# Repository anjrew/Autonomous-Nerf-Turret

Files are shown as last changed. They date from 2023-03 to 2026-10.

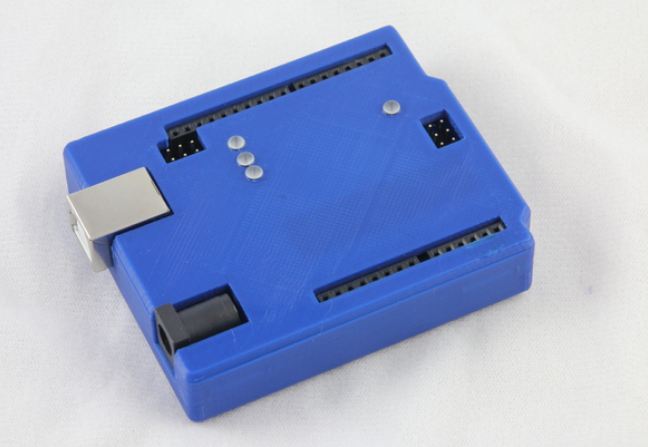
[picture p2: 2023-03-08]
cad/arduino-uno-case/Capture.JPG

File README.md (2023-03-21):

# Autonomous Nerf Turret

A project dedicated to creating a fully autonomous, AI-powered Nerf gun. The turret is equipped with a camera, allowing it to detect and track human targets. 

## Getting started

This project was built on MacOS on top of these main dependencies:
  - bash
  - conda
  - [CMake](https://cmake.org/download/)

 If these are installed then run the following command in the project root to get the rest of the dependencies and setup the virtual environment:
 ```bash
source bin/init.sh
 ```

 When coming back to the project to reactivate the environment run the following in the project root:
 ```bash
 source bin/activate.sh
 ```

## Important info

The files and folders in this project depend on each other and this means that the folder structure is important. If any folder structure or file is changed it could break some functionality.

## Project structure

This project is driven by domain where each domain component lies in a folder in the 'components' directory. Each sub domain folder contains files that relate to the part of the project associated with that domain.

For example:
  - The **camera_vision** folder contains files related to the computer vision tasks associated with face tracking.
  - The **arduino** folder contains files related to the task of moving and controlling the stepper motor through the Arduino

  ## Versions

  - 1 - Stepperonline Nema 17 Stepper Motor, 45 Ncm, 1.5 A, 12 V, 39 mm, 4-Wire 1.8 Deg Stepper Motor with 1 m Wire for 3D Printers:
    - When firing under full load with stepper servo and gun the circuit pulls around 1.8A when running and 2.1A when starting up
    - Of this the gun motors take up around 1.1A at full speed and 1.9A when starting up
    - On stand still the circuit uses 0.08A

  ## Good combination configurations

| HEADLESS | Skip Frames | IMG Comp | Y-speed,smooth,lim | X-speed,smooth,lim | target_type | faces | objects | model |
|---|---|---|---|---|---|---|---|---|
| True | 500 | 4x | 2,1,10 | 30,1,60 | person | True  | True | yolov8n-seg.pt |

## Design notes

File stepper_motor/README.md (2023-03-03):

# Stepper control notes

- Pulsing the **step** pin on the stepper motor driver will cause the motor to move one step
- The longer the time between pulses the slower the step will take place
- Change the direction pin between high/low to change direction of the spin to clockwise vs anti clockwise

# Key notes
- Input voltage is set to 12.5v

## Setup 

Before you start programming your Arduino and start using the driver there is one very important thing you need to do that a lot of people forget: set the current limit!

You must measure a reference voltage and adjust the on-board potentiometer accordingly. You will need a small screwdriver, a multimeter to measure the reference voltage, and alligator test leads

Image of how to do it

To measure the reference voltage, the driver needs to be powered. The A4988 only needs power via VDD (5V) and you need to connect RST and SLP together, otherwise the driver won’t turn on. It’s best to disconnect the stepper motor while you do this.

The next step is to calculate the current limit with the following formula: **Current Limit = Vref / (8 × Rcs)**

Refactored to get the Vref this is **Vref = Current Limit * (8 × Rcs)**

The Rcs is the current sense resistance. If you bought a A4988 driver from Pololu before January 2017, the Rcs will be 0.050 Ω. Drivers sold after that have 0.068 Ω current sense resistors.

The calculation for the Vref that was acquired on the first time was:
Vref = 0.380 = 0.7A * (8 * 0.068)

## Communication over serial

A raw none stringified JSON string can be sent over serial and be received by the Arduino with optional direction and speed properties.

## Calculating RPM value

The motor here has 200 steps in one revolution
So 200 steps per second would equal 60 RPM

So time per step in seconds = 60 * steps_per_revolution
timeper step

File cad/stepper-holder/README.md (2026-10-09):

# Stepper motor holder (NEMA 17 / 17HS4023)

Parametric OpenSCAD holder for the elevation stepper motor used by the turret.

## Files

- `stepper_holder.scad` — parametric source; edit the values at the top
- Export an STL with OpenSCAD: open the file, press **F6** (render), then
  **File → Export → Export as STL**

## Default dimensions

| Feature | Value |
| --- | --- |
| Motor face | 42.3 mm (17HS4023) |
| Bolt pattern | 31 mm square, M3 (3.4 mm clearance) |
| Centring boss clearance | 22.5 mm |
| Shaft clearance | 8 mm |
| Plate thickness | 5 mm |
| Cradle wall height | 18 mm |

The holder has a face plate with the NEMA 17 bolt pattern, a three-sided
cradle that holds the motor body (open on top for drop-in and at the back for
wiring), and two side flanges with screw slots for mounting to the turret.

Tune the parameters for your exact motor, then re-render and export.

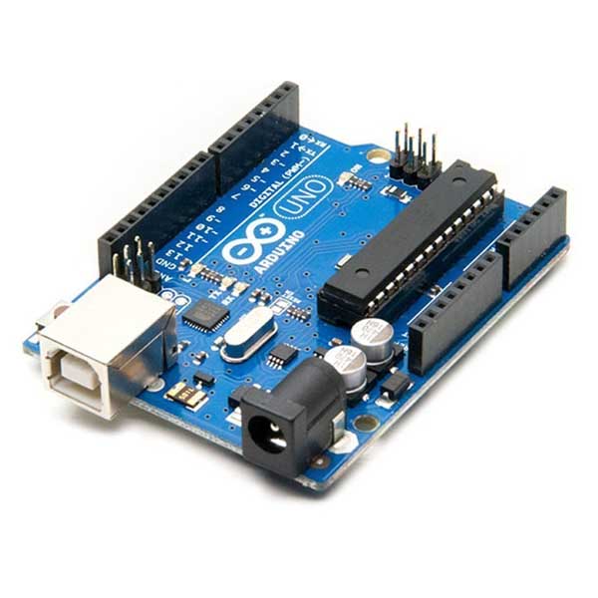
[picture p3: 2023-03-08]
cad/arduino-uno-case/uno_r3.jpg

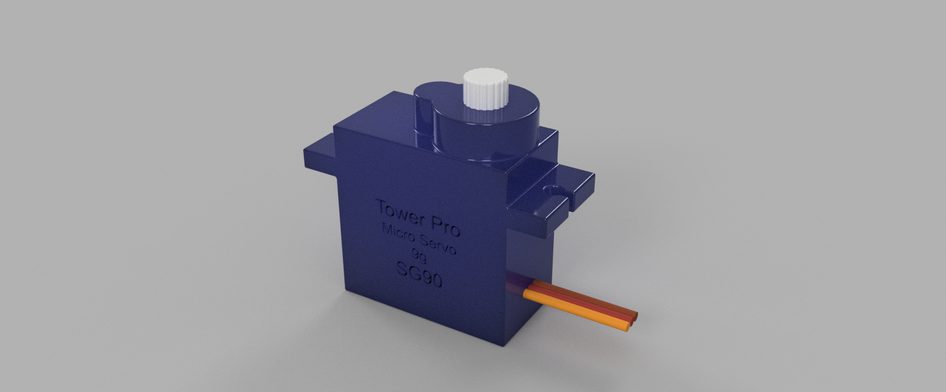
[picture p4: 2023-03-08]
cad/servo-sg90/Tower Pro SG90 Servo v7.png

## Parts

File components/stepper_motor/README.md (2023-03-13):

# Stepper control notes

- Pulsing the **step** pin on the stepper motor driver will cause the motor to move one step
- The longer the time between pulses the slower the step will take place
- Change the direction pin between high/low to change direction of the spin to clockwise vs anti clockwise

# Key notes
- Input voltage is set to 12.5v

## Setup 

Before you start programming your Arduino and start using the driver there is one very important thing you need to do that a lot of people forget: set the current limit!

You must measure a reference voltage and adjust the on-board potentiometer accordingly. You will need a small screwdriver, a multimeter to measure the reference voltage, and alligator test leads

Image of how to do it

To measure the reference voltage, the driver needs to be powered. The A4988 only needs power via VDD (5V) and you need to connect RST and SLP together, otherwise the driver won’t turn on. It’s best to disconnect the stepper motor while you do this.

The next step is to calculate the current limit with the following formula: **Current Limit = Vref / (8 × Rcs)**

Refactored to get the Vref this is **Vref = Current Limit * (8 × Rcs)**

The Rcs is the current sense resistance. If you bought a A4988 driver from Pololu before January 2017, the Rcs will be 0.050 Ω. Drivers sold after that have 0.068 Ω current sense resistors.

The calculation for the Vref that was acquired on the first time was:
Vref = 0.380 = 0.7A * (8 * 0.068)

## Communication over serial

A raw none stringified JSON string can be sent over serial and be received by the Arduino with optional direction and speed properties.

## Calculating RPM value

The motor here has 200 steps in one revolution
So 200 steps per second would equal 60 RPM

So time per step in seconds = 60 * steps_per_revolution

## Key points

Here are some key points after testing the motor at different half step speeds

- The slowest the motor can go is 16000us between each half step
  - That means that the slowest the motor can do one step is 32000us
  - So 32000us x 200 Steps for one revolution is 6400000us
  - That means that it does one revolution in 6.4 seconds at min speed
  - Max Revolutions per minute = 60 seconds/0.16 seconds = 375 revolutions per minute (RPM)
  - Min Revolutions per minute = 60 seconds/6.4 seconds = 9.375 revolutions per minute (RPM)

- The fastest the motor can go is 400us between each half step
  - That means that the fastest the motor can do one step is 800us
  - So 800us x 200 Steps for one revolution is 160000us
  - That means that it does one revolution in 0.16 seconds at max speed
  - Max Revolutions per minute = 60 seconds/0.16 seconds = 375 revolutions per minute (RPM)

- In summery the min/max RPM is ~9rpm/375rpm 

## Sources of information
 - See the [Documentation folder](./documentation/)
 - For info on the 2N3904 Resistor see [this](https://www.homemade-circuits.com/understanding-transistor-2n3904/) link
 - [Servo Motor](https://www.amazon.de/dp/B09WRBHSVD?ref=ppx_yo2ov_dt_b_product_details&th=1) for azimuth 
 - [LM2596 Buck Converter](https://www.amazon.de/Yizhet-LM2596-Buck-Converter-3-0/dp/B0823P6PW6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)

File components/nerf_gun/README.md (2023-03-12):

# Nerf gun

The Nerf gun used is a [Hyper-Fire Elite](https://www.amazon.de/-/en/Hasbro-N-Strike-Hyper-Fire-Blaster-B5573F03/dp/B01N2GMZ3M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)

Gun Image

Info:
 - [Video](https://www.youtube.com/watch?v=H6EAR7Sc_Ms) on modification showing how to dismantle and wiring information
 - [5v Relay](https://www.reichelt.de/de/de/entwicklerboards-relais-modul-5-v-srd-05vdc-sl-c-debo-relay-5v-p239148.html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)

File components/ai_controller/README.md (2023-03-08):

# AI controller

The AI controller subscribes to the output of the camera vision and sends controls to the serial driver component:

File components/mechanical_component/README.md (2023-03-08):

# Mechanical Design

Here you will find the CAD design that was made in fusion 360 and other components that went into designing the frame pullies and bearings

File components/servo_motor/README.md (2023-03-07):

# Servo motor

[The servo motor](https://m.media-amazon.com/images/I/91KkRAtEPSL._AC_SL1500_.jpg)

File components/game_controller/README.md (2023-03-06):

# Game controller

The game controller component takes input from a game controller in order to send messages to the serial driver to control the gun turret manually.

This controller was made with the GC-1 Series Wired controller in mind. Model NO: GC102

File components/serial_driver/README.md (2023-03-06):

# Driver

The driver is responsible for managing the inputs from whatever controller source and forwarding the messages to the motors via serial

Examples of controller sources are:
  - ai model
  - game controller

The driver is a server that listens on a port and waits for commands from any controller and executes forwards the commands tot he

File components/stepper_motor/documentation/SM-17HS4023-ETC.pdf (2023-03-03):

# SM-17HS4023

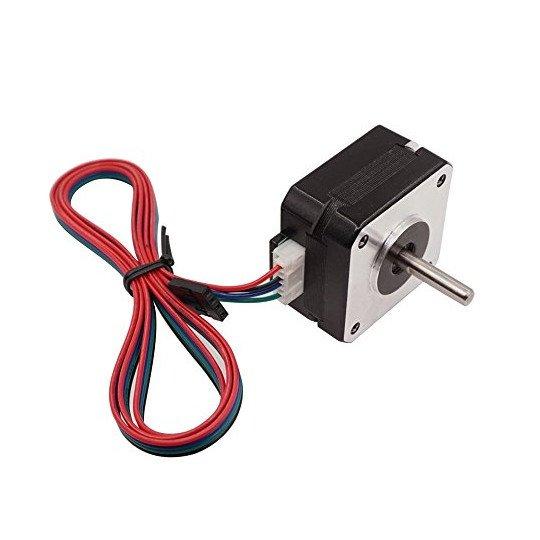
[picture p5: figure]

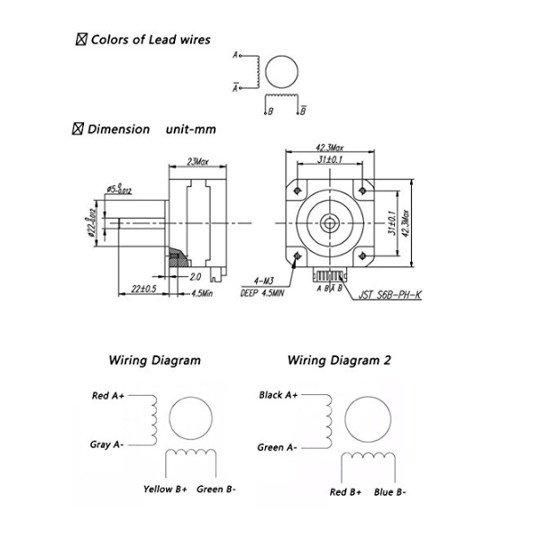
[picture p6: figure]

HARDWARE

- Shaft diameter 5mm
- Shaft Length 21mm
- 4 wires / 2 Phase
- Voltage: 12 V
- Current: 0.7 A / Phase
- Resistance: 4.0 ± 10% Ω / Phase
- Inductance: 3.2 ± 20% mH / Phase
- Holding Torque: 14 N. cm
- Insulation Class: B
- Step Angle: 1.8 ± 5% / Step
- Item Size: 42 * 42 * 23mm

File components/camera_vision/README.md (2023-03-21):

# Vision

This code includes computer vision algorithms for object detection and tracking. 

## Info
  - A [video](https://www.youtube.com/watch?v=5yPeKQzCPdI&list=PLVlbw1IZ2gnswgwYW9jXkEz43f3j7qs25&index=77) of how to use the face recognition library 
  - A guide on setting up the [YOLO object detection](https://docs.ultralytics.com/tasks/detect/) 
  - Speed optimization for inference with script parameters:
    - Skip 10 frames
    - Use 4x compression

## Image processing times

These experiments were made on 2018 Macbook pro and processing as a video feed:

| MODEL | Task | Preprocessing  |  Inference | Post processing | Detect total time  | Loop total time  | Showing camera |
|---|---|---|---|---|---| ---| --- |
| yolov8n-seg.pt  | Detection | +/- 1ms mean | +/- 220ms mean | +/- 1ms mean | +/- 222ms mean | +/- 222ms mean | [x] |
| yolov8n-seg.pt  | Detection | unknown | unknown | unknown | unknown | +/- 230ms mean | [x] |
| yolov8n.pt | Detection | +/- 1ms mean | +/- 168s mean | +/- 1ms mean | +/- 170ms mean | +/- 170ms mean | [x] |

The findings indicate the most of the image processing time is in inference and the pre and post processing time is negligible.
Segmentation takes 30% more time to process than bounding box detection.

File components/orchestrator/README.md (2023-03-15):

# Orchestrator

This folder contains files related to the orchestrator which manages all the other services together to create complete solutions

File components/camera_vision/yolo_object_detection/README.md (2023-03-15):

# Yolo Object Detection

## Notes

  - How to improve performance with library [Link](https://github.com/nebuly-ai/nebullvm/blob/main/notebooks/speedster/pytorch/Accelerate_PyTorch_YOLOv8_with_Speedster.ipynb)
  - How to improve performance by exporting [Link](https://docs.ultralytics.com/modes/export/)

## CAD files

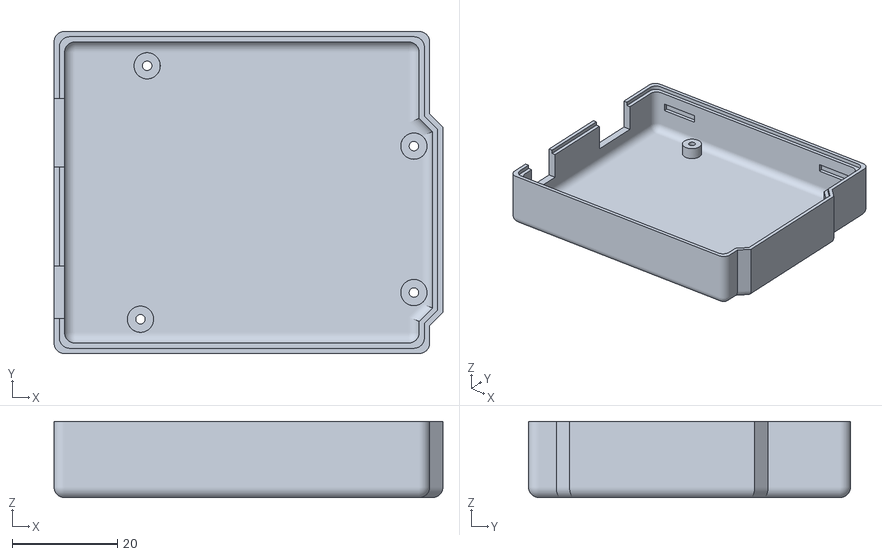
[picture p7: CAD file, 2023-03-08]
cad/arduino-uno-case/arduino_uno_bottom.stl
74.1 x 61.3 x 14.5

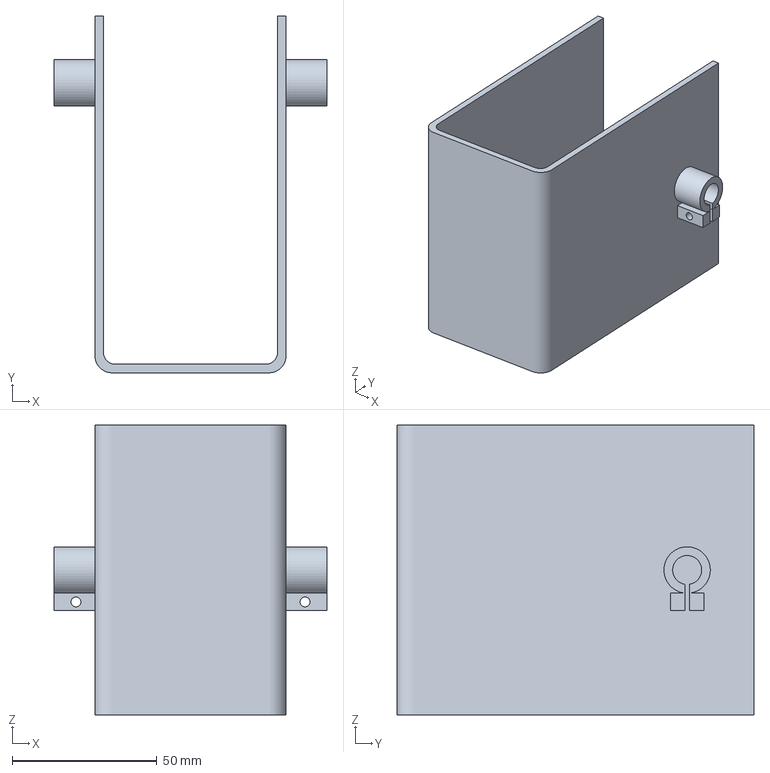
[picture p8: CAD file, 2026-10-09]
cad/gun-cradle/gun_cradle.3mf
94.0 x 123.0 x 100.0 mm

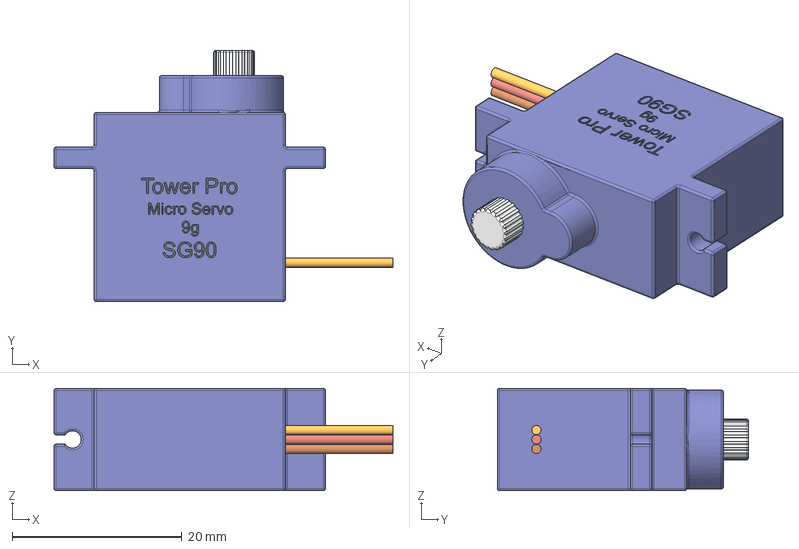
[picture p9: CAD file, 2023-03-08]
cad/servo-sg90/Tower Pro SG90 Servo v7.step
40.0 x 29.7 x 12.1 mm

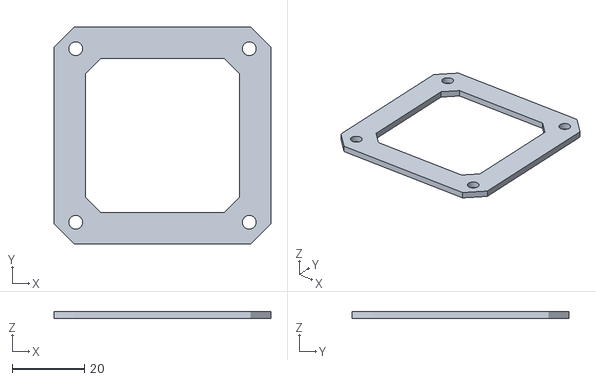
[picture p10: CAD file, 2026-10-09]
cad/stepper-holder/stepper_outer_plate.stl
60.0 x 60.0 x 2.00

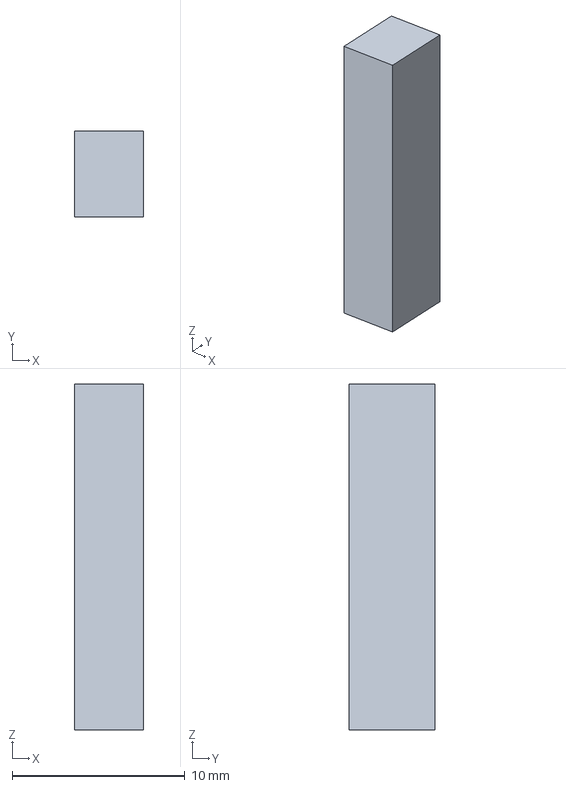
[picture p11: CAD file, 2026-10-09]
cad/trigger-block/trigger_block.3mf
4.00 x 5.00 x 20.0 mm

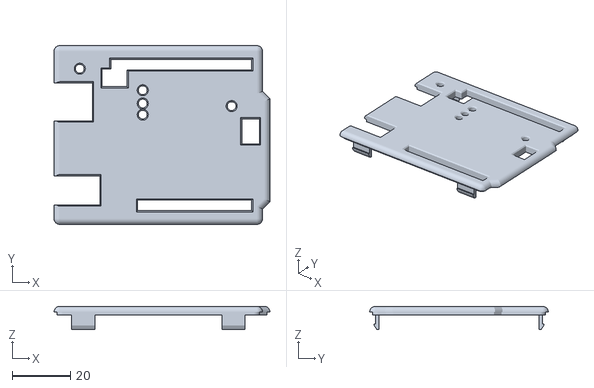
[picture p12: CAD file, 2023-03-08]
cad/arduino-uno-case/arduino_uno_top.stl
74.1 x 61.3 x 8.00

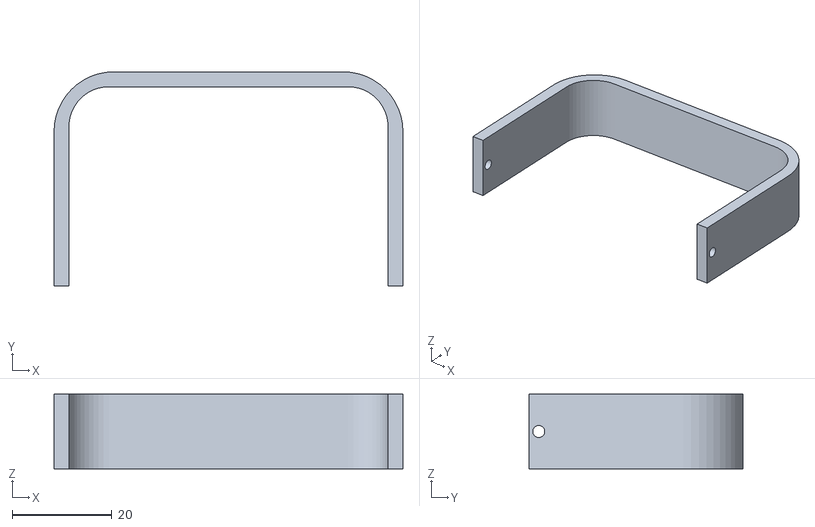
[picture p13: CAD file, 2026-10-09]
cad/gun-cradle/gun_cradle_plain_40.stl
70.0 x 43.0 x 15.0

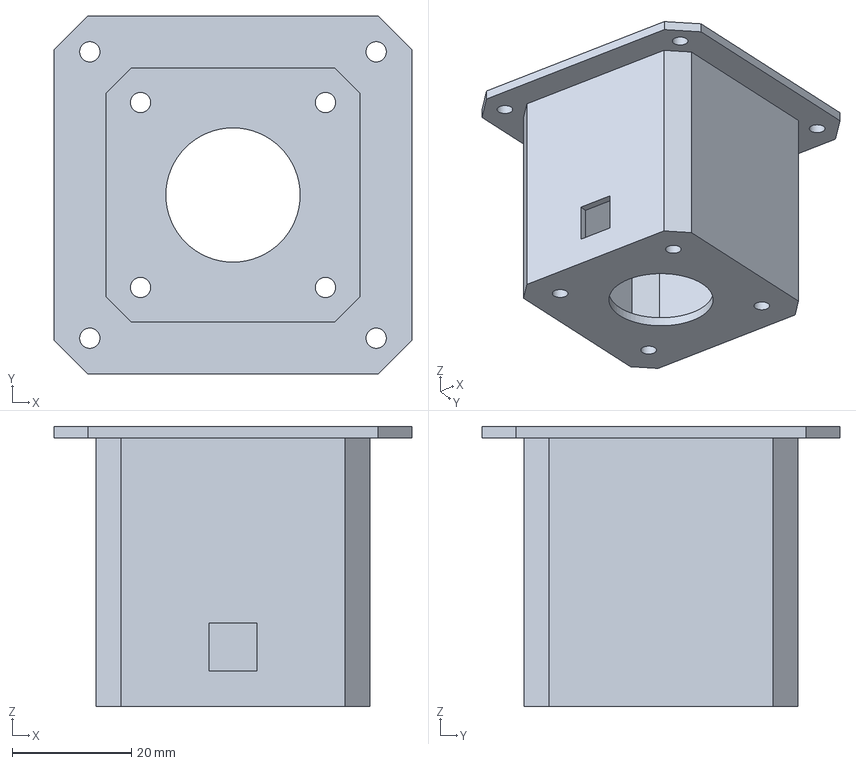
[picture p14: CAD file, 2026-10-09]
cad/stepper-holder/stepper_holder.3mf
60.0 x 60.0 x 47.0 mm

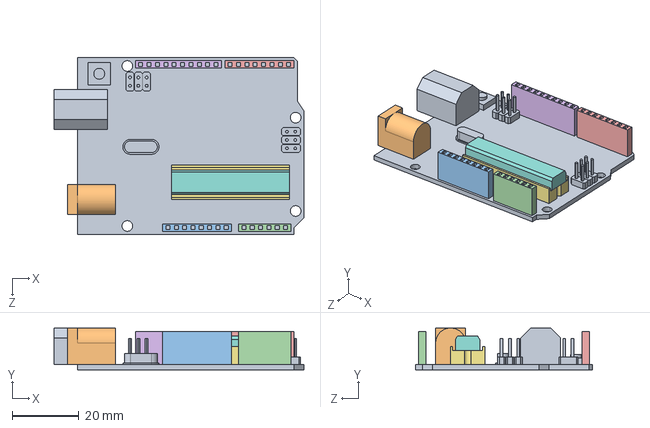
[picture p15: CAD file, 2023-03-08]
cad/arduino-uno-case/uno.STEP
75.0 x 12.6 x 53.0 mm

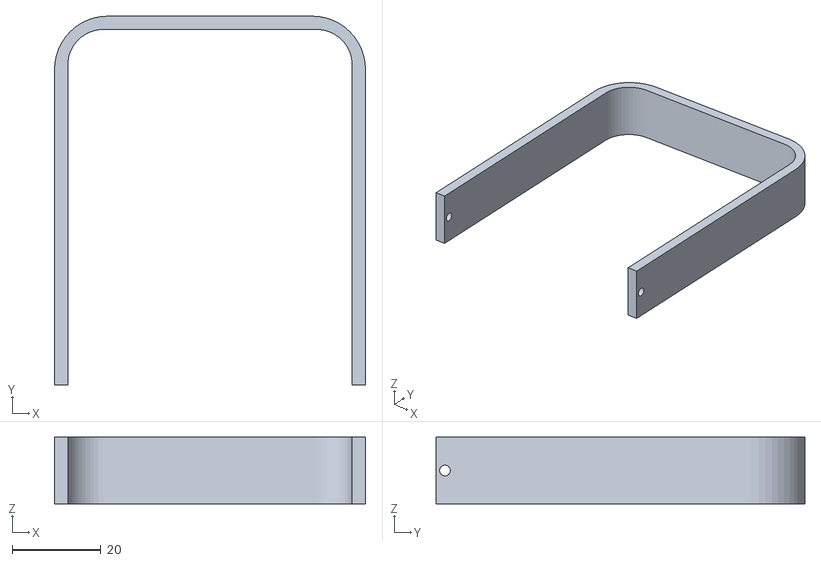
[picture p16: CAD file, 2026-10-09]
cad/gun-cradle/gun_cradle_plain.stl
70.0 x 83.0 x 15.0

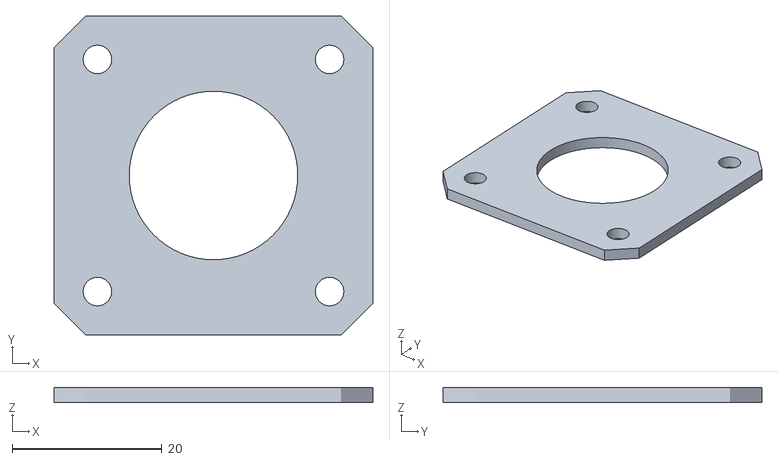
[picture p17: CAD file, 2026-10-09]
cad/stepper-holder/stepper_inner_plate.stl
42.6 x 42.6 x 2.00

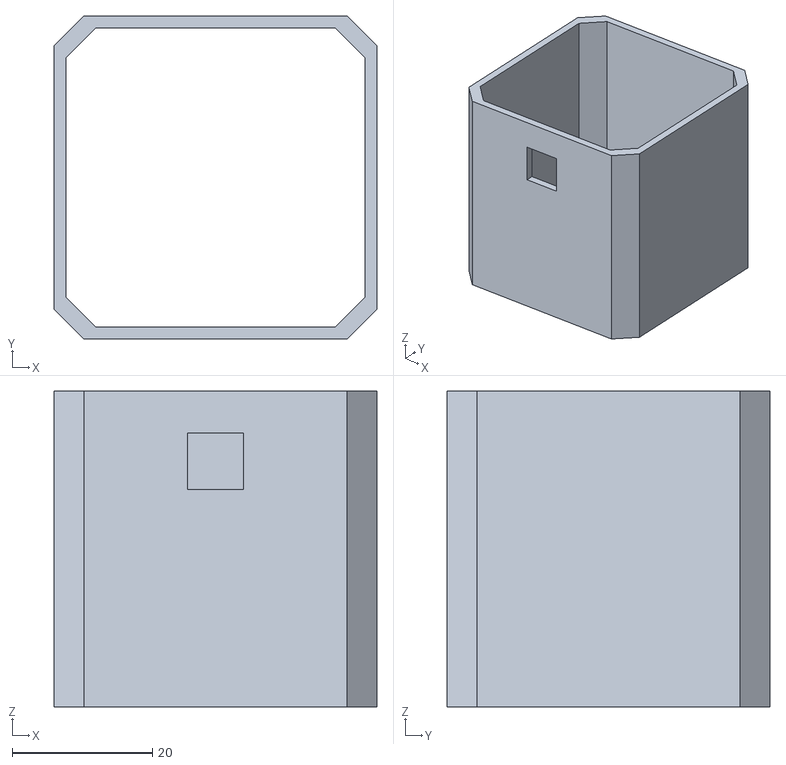
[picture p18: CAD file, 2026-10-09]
cad/stepper-holder/stepper_cradle.stl
46.0 x 46.0 x 45.0

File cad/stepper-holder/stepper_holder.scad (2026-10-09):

// Parametric NEMA 17 stepper motor holder (two end plates + cradle)
// Export: F6 to render, then File > Export > Export as STL
// All dimensions in mm.

/* [Plates] */
// Inner plate: fits inside the cradle bore and bolts to the motor face
inner_plate = true;
// Outer plate: sits on the outside of the far end and mounts to the panel
outer_plate = true;
// Plate thickness
plate_thickness = 2.0;
// Outer plate size (square) and corner chamfer flat
plate_size        = 60.0;
plate_corner_flat = 8.0;
// Corner mounting screw holes (M3 clearance)
corner_hole_dia   = 3.8;
corner_hole_inset = 6.0;

/* [Motor cutout] */
// Motor face size (measured: 42 mm)
motor_face   = 42.0;
// Total clearance added to the cavity so the motor isn't too tight
motor_clearance = 0.6;
// NEMA 17 bolt hole spacing
bolt_spacing = 31.0;
// Motor bolt hole diameter (M3 clearance)
bolt_dia     = 3.8;
// Centring boss clearance
boss_dia     = 22.5;
// Shaft clearance
shaft_dia    = 8.0;
// Length of the flat on each tapered corner (motor is octagonal)
corner_flat  = 6.0;

/* [Cradle] */
// Add the three-sided cradle that wraps the motor body
include_cradle = true;
// Cradle wall thickness
wall_thickness = 2.0;
// Motor body length (measured: 45 mm deep)
motor_length   = 45.0;

/* [Wire cutout] */
// Distance of the slot centre from the motor-end plate
wire_slot_from_plate = 10.0;
// Slot width (along the plate)
wire_slot_width      = 8.0;
// Slot height (along the motor axis)
wire_slot_height     = 8.0;
// Which wall the slot breaks through: -1 = -Y wall, +1 = +Y wall
wire_slot_side       = -1;

/* [Parts] */
// Which piece(s) to lay out: "all", "inner", "outer", "cradle"
part = "all";

/* [Quality] */
$fn = 64;

module octagon_prism(height, across_flats, flat, center_z = 0) {
    // Square across flats with 45 degree corner cuts leaving `flat`.
    half = across_flats / 2;
    cut = flat / sqrt(2);
    translate([0, 0, center_z])
        linear_extrude(height = height, center = true)
            polygon(points = [
                [ half,         half - cut],
                [ half - cut,    half],
                [-(half - cut),  half],
                [-half,         half - cut],
                [-half,        -(half - cut)],
                [-(half - cut), -half],
                [ half - cut,   -half],
                [ half,        -(half - cut)],
            ]);
}

module motor_cutout() {
    // Bolt pattern, centring boss and shaft clearance
    for (x = [-1, 1], y = [-1, 1]) {
        translate([x * bolt_spacing / 2, y * bolt_spacing / 2, 0])
            cylinder(d = bolt_dia, h = plate_thickness * 4, center = true);
    }
    cylinder(d = boss_dia, h = plate_thickness * 4, center = true);
    cylinder(d = shaft_dia, h = plate_thickness * 4, center = true);
}

module inner_plate() {
    // Sits inside the cradle bore at the motor end and bolts to the motor.
    z_motor_end = -plate_thickness / 2 - plate_thickness / 2;
    difference() {
        octagon_prism(plate_thickness, motor_face + motor_clearance, corner_flat, z_motor_end);
        motor_cutout();
    }
}

module outer_plate() {
    // Sits on the outside of the far end and mounts to the panel.
    z_far = -plate_thickness / 2 - motor_length - plate_thickness / 2;
    difference() {
        octagon_prism(plate_thickness, plate_size, plate_corner_flat, z_far);
        // Central opening so the motor's shape can pass through the middle
        octagon_prism(plate_thickness * 4, motor_face + motor_clearance, corner_flat, z_far);
        for (x = [-1, 1], y = [-1, 1]) {
            translate([x * (plate_size / 2 - corner_hole_inset),
                       y * (plate_size / 2 - corner_hole_inset), z_far])
                cylinder(d = corner_hole_dia, h = plate_thickness * 4, center = true);
        }
    }
}

module motor_cradle() {
    if (include_cradle) {
        // Cradle extends behind the plate to hold the motor body.
        translate([0, 0, -plate_thickness / 2 - motor_length / 2]) {
            difference() {
                // Outer shell with the same chamfered corner profile
                octagon_prism(motor_length,
                              motor_face + 2 * wall_thickness,
                              corner_flat);
                // Motor cavity (octagonal, matches the tapered corners)
                octagon_prism(motor_length + 2, motor_face + motor_clearance, corner_flat);
                // Wiring exit slot (parameters under [Wire cutout])
                translate([0,
                           wire_slot_side * (motor_face + motor_clearance) / 2,
                           motor_length / 2 - wire_slot_from_plate])
                    cube([wire_slot_width, wall_thickness + 6, wire_slot_height],
                         center = true);
            }
        }
    }
}

module stepper_holder() {
    if (part == "all") {
        // Assembled: inner plate attached at the motor end (bottom) of the
        // cradle, outer frame attached at the far end (top).
        inner_plate();
        motor_cradle();
        outer_plate();
    } else if (part == "inner") {
        inner_plate();
    } else if (part == "outer") {
        outer_plate();
    } else {
        motor_cradle();
    }
}

stepper_holder();

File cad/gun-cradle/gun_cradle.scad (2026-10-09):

// Cradle for the Nerf gun to sit in (open-top tray)
// Export: F6 to render, then File > Export > Export as STL
// All dimensions in mm.

/* [Cavity] */
// Internal cavity the gun sits in
cavity_width  = 60.0;   // X
cavity_height = 100.0;  // Z
cavity_length = 120.0;  // Y (20 mm longer)

/* [Walls] */
wall_thickness = 3.0;
// No base: the cradle is open at both ends (set > 0 to add a floor)
base_thickness = 0.0;

/* [Corner radii] */
// Radius on the inside corners of the cavity
inner_corner_radius = 4.0;
// Radius on the outside corners of the cradle
outer_corner_radius = 6.0;

/* [Base fillet] */
// Fillet where the cavity floor meets the walls
floor_fillet = 3.0;

/* [Open side] */
// Completely open one of the short sides
open_short_side = true;
// Which short side: -1 = -X, +1 = +X
open_side = -1;

/* [Mounts] */
// Pipe sockets coming off each side that a 10 mm pipe slides into
mount_pipes    = true;
pipe_dia       = 10.0;  // pipe bore (slip fit)
socket_outer_dia = 16.0;
socket_length  = 15.0;  // how far the socket sticks out
// Socket height as a fraction of the wall (0 = bottom edge, 0.5 = centred)
socket_z_fraction = 0.6;
// Distance of the socket centre from the closed end, along Y
socket_y = 100.0;
// Grub screw hole through the socket wall (kept for reference; unused)
grub_dia = 3.0;
// Clamp hardware
clamp_slit   = 1.6;  // slit width
clamp_ear_h  = 6.0;  // how far the clamp ears stick out
clamp_ear_w  = 5.0;  // ear width each side of the slit
clamp_bolt_dia = 3.4; // M3 bolt clearance
clamp_nut_af   = 5.5; // M3 hex nut across flats

/* [Capsule opening] */
// Capsule slot through the closed short wall (centred in X)
capsule_length = 35.0;
capsule_width  = 10.0;
// Distance from the bottom edge to the start of the capsule
capsule_from_bottom = 13.0;

/* [Quality] */
$fn = 48;

outer_width  = cavity_width  + 2 * wall_thickness;
outer_length = cavity_length + 2 * wall_thickness;
outer_height = cavity_height + base_thickness;

module rounded_rect(width, length, radius) {
    offset(r = radius) square([width - 2 * radius, length - 2 * radius], center = true);
}

module pipe_socket() {
    // Split-clamp pipe socket (local axis = Z). A slit runs along the top
    // between two ears; an M3 bolt through the ears squeezes the socket onto
    // the pipe, and one ear takes a trapped hex nut.
    r_out = socket_outer_dia / 2;
    ear_x = r_out + clamp_ear_h / 2 - 2; // overlap the tube so they fuse
    ear_y = clamp_slit / 2 + clamp_ear_w / 2;
    difference() {
        union() {
            cylinder(d = socket_outer_dia, h = socket_length, center = true);
            for (y = [-1, 1])
                translate([ear_x, y * ear_y, 0])
                    cube([clamp_ear_h, clamp_ear_w, socket_length], center = true);
        }
        cylinder(d = pipe_dia, h = socket_length + 2, center = true);
        translate([(r_out + clamp_ear_h) / 2 + 0.5, 0, 0])
            cube([r_out + clamp_ear_h + 2, clamp_slit, socket_length + 2], center = true);
        translate([ear_x, 0, 0])
            rotate([90, 0, 0])
                cylinder(d = clamp_bolt_dia, h = 2 * clamp_ear_w + clamp_slit + 4, center = true);
        translate([ear_x, clamp_slit / 2 + clamp_ear_w - 1.6, 0])
            cylinder(d = clamp_nut_af / cos(30), h = 3.2, center = true, $fn = 6);
    }
}

module gun_cradle() {
    difference() {
        // Outer shell with rounded outside corners, squared off at the open end
        union() {
            linear_extrude(height = outer_height, center = true)
                rounded_rect(outer_width, outer_length, outer_corner_radius);
            if (open_short_side) {
                translate([0, open_side * (outer_length / 2 - outer_corner_radius / 2), 0])
                    linear_extrude(height = outer_height, center = true)
                        square([outer_width, outer_corner_radius], center = true);
            }
            // Pipe sockets coming off each side at the bottom
            if (mount_pipes) {
                for (x = [-1, 1]) {
                    translate([x * (outer_width / 2 + socket_length / 2 - 1),
                               -outer_length / 2 + socket_y,
                               -outer_height / 2 + socket_z_fraction * outer_height])
                        rotate([0, 90, 0])
                            pipe_socket();
                }
            }
        }

        // Cavity with rounded inside corners, open at the top
        translate([0, 0, base_thickness / 2 + 0.5])
            linear_extrude(height = cavity_height + 1, center = true)
                rounded_rect(cavity_width, cavity_length, inner_corner_radius);

        // Capsule opening through the closed short wall
        translate([0, -open_side * outer_length / 2,
                   -outer_height / 2 + capsule_from_bottom + capsule_length / 2])
            rotate([90, 0, 0])
                linear_extrude(height = wall_thickness + 4, center = true)
                    hull() {
                        translate([0, -(capsule_length - capsule_width) / 2]) circle(d = capsule_width);
                        translate([0,  (capsule_length - capsule_width) / 2]) circle(d = capsule_width);
                    }

        // Remove one short side (±Y walls, the 60 mm-wide faces) entirely
        if (open_short_side) {
            translate([0, open_side * (cavity_length / 2 + wall_thickness / 2 + 0.5), 0])
                cube([outer_width + 2, wall_thickness + 1, outer_height + 2], center = true);
            // Square the inner cavity corners at the open end as well
            translate([0, open_side * (cavity_length / 2 - inner_corner_radius / 2), 0])
                linear_extrude(height = cavity_height + 2, center = true)
                    square([cavity_width, inner_corner_radius], center = true);
        }
    }
}

gun_cradle();

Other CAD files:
cad/gun-cradle/gun_cradle_plain.scad
cad/gun-cradle/gun_cradle_plain_40.scad
cad/arduino-uno-case/uno.SLDPRT
cad/base/Cannon Base.f3d
cad/base/base v1.f3d
cad/base/base v2.f3d
cad/base/base v4.f3z
cad/base/cannon_base.f3d
cad/gun-cradle/gun_cradle.stl
cad/gun/Nerf_gun.f3d
cad/servo-sg90/base v4.f3z
cad/servo-sg90/base v5.f3z
cad/servo-sg90/base v7.f3z
cad/servo-sg90/base v8.f3z
cad/servo-sg90/base v9.f3z
cad/stepper-holder/stepper_holder.stl
cad/trigger-block/trigger_block.scad
cad/trigger-block/trigger_block.stl

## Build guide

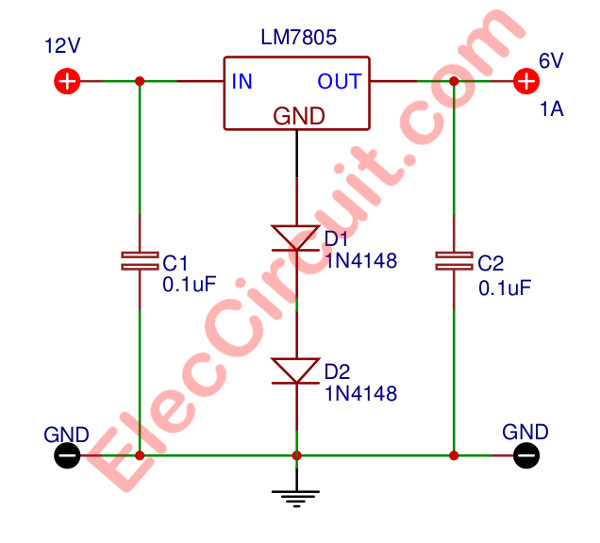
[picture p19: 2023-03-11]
components/stepper_motor/documentation/the-step-down-12-volts-to-6-volts-dc-converter-1.jpg

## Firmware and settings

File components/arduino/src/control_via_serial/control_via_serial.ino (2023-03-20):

/*Example sketch to control a stepper motor with A4988 stepper motor driver and Arduino without a library. More info: https://www.makerguides.com */
#include <Servo.h>
#include "turret_control.h"
#include <stdint.h>


// Define stepper motor connections and steps per revolution:
#define dirPin 2
#define stepPin 3
#define shootPin 10
#define azimuthServoPin 9
#define stepsPerRevolution 200

// Define the initial timer interval in milliseconds. Start with max value
#define INITIAL_TIMER_INTERVAL 0;

// Define a timer interval variable
unsigned long timerIntervalMs = INITIAL_TIMER_INTERVAL;

// The default value is the value observed when testing in MILLISECONDS
uint8_t meanSerialProcessingTimeMs = 69;

/*
 * Alternates the PIN from HIGH to LOW on each half step
*/
bool alternator = false;

int azimuth_angle_deg = 90;


// The limits of the values to be set for the motor half step
const int SLOWEST_HALF_STEP_MILLISECONDS = 5;
const int FASTEST_HALF_STEP_MILLISECONDS = 1;
const int SLOWEST_STEP_SPEED = 80; // in milli seconds which is achieved by making 1 step at slowest possible seed and then waiting until 1 second has passed


const uint8_t SLOWEST_SPEED = 0;
const uint8_t FASTEST_SPEED = 10;
bool isFiring = false; // Records the isFirong state for debugging purposes

const uint8_t MAX_AZIMUTH_DEG_RANGE= 180;

Servo azimuthServo;  // create servo object to control a servo


bool processSerialInput() {
  
  // Read the encoded motor command from serial input
  uint8_t serialBuffer[2];
  
  if (Serial.available() >= 2) {
    unsigned long startOfSerialProcess = micros();
    uint8_t serialBuffer[2];  // create a buffer to store the read uint8_ts

    Serial.readBytes(serialBuffer, 2);  // read two uint8_ts into the buffer
    
    // Decode the motor command
    TurretSettings decodedValues = decode(serialBuffer);
    int speedIn = decodedValues.speed;

    if (speedIn < 1) {
      // If the speed is zero then set interval to zero so it is ignored in the loop
      timerIntervalMs = 0;
    } else {
     unsigned long stepMs = mapRange(speedIn, SLOWEST_SPEED, FASTEST_SPEED, SLOWEST_STEP_SPEED, FASTEST_HALF_STEP_MILLISECONDS);
//      Serial.print("Mapped Speed: ");
//      Serial.print(speedIn);
//      Serial.print(" to stepMs Speed: ");
//      Serial.println(stepMs);
      timerIntervalMs = max(stepMs < FASTEST_HALF_STEP_MILLISECONDS ? FASTEST_HALF_STEP_MILLISECONDS : stepMs, 0);
    }
    

    int newAzimuth = azimuth_angle_deg +  decodedValues.azimuth;
    if (newAzimuth >= 0 && newAzimuth <= MAX_AZIMUTH_DEG_RANGE) {
      azimuthServo.write(newAzimuth);
      azimuth_angle_deg = newAzimuth;
    }

    
    digitalWrite(dirPin, decodedValues.isClockwise ? LOW : HIGH);

    isFiring = decodedValues.isFiring;

    digitalWrite(shootPin, isFiring ? HIGH: LOW);   
    

   
    meanSerialProcessingTimeMs = (meanSerialProcessingTimeMs + micros() - startOfSerialProcess) / 2;
    // Serial.print(" - azimuth: ");
    // Serial.print(decodedValues.azimuth);
    // Serial.print(" - speed: ");
    // Serial.println(decodedValues.speed);
    // Serial.print(" - isClockwise: ");
    // Serial.println(decodedValues.isClockwise);
    // Serial.print(" - isFiring: ");
    // Serial.println(decodedValues.isFiring);

    return true;
  } else {
    return false;
  }
}


void setup() {
  // Start serial for communication
  Serial.begin(9600);
  // Declare pins as output:
  pinMode(stepPin, OUTPUT);
  pinMode(dirPin, OUTPUT);

  // Setup the servo motor
  azimuthServo.attach(azimuthServoPin ,600,2300);  // (pin, min, max)

  // Setup pin to shoot
  pinMode(shootPin, OUTPUT);

//  Serial.print("Current configuration");
//  Serial.print("SLOWEST_HALF_STEP_MILLISECONDS: ");
//  Serial.println(SLOWEST_HALF_STEP_MILLISECONDS);
//  Serial.print(" - FASTEST_HALF_STEP_MILLISECONDS: ");
//  Serial.println(FASTEST_HALF_STEP_MILLISECONDS);
//  Serial.print(" - SLOWEST_STEP_SPEED: ");
//  Serial.println(SLOWEST_STEP_SPEED);
//  Serial.print(" - STEP_MILLI_SECONDS_RANGE: ");
//  Serial.println(STEP_MILLI_SECONDS_RANGE);
//  Serial.print(" - SLOWEST_SPEED: ");
//  Serial.println(SLOWEST_SPEED);
//  Serial.print(" - FASTEST_SPEED: ");
//  Serial.println(FASTEST_SPEED);
//  Serial.print(" - ORDINAL_SPEED_RANGE: ");
//  Serial.println(ORDINAL_SPEED_RANGE);
//  Serial.print(" - MAX_AZIMUTH_DEG_RANGE: ");
//  Serial.println(MAX_AZIMUTH_DEG_RANGE);

  Serial.println("Send Commands !");
}


void loop() {
//  Serial.print("T:");
//  Serial.println(timerIntervalMs);
  
  bool had_serial_input = processSerialInput();
  uint8_t delay_time = had_serial_input ? meanSerialProcessingTimeMs/1000 : 0;
//  Serial.print("timerIntervalMs " );
//  Serial.println(timerIntervalMs );

  // Use this logic if the value is slower than the stepper motor can handle
  if (timerIntervalMs > SLOWEST_HALF_STEP_MILLISECONDS) {
//    Serial.println('s');
    digitalWrite(stepPin, alternator ? HIGH : LOW );
    alternator = !alternator;
    delay(FASTEST_HALF_STEP_MILLISECONDS);
//    Serial.println('m');
    digitalWrite(stepPin, alternator ? HIGH : LOW );
    alternator = !alternator; 
    int secondWaitTime = timerIntervalMs - FASTEST_HALF_STEP_MILLISECONDS - delay_time;
//    Serial.println('p');
//    Serial.println(secondWaitTime);
    delay(secondWaitTime);
//    Serial.print('w');
//    Serial.println(secondWaitTime);
//    Serial.print('t');
//    Serial.println(secondWaitTime);

     
  } else if (timerIntervalMs > 1) {
//    Serial.println('g');
    unsigned long interval_step = timerIntervalMs - delay_time;

    delay(interval_step);
    digitalWrite(stepPin, alternator ? HIGH : LOW );
    alternator = !alternator;
  } else {
//    Serial.println('n');
      // If timer interval is Zero then just do nothing
      
  }

  // Serial.print("loop isFiring: ");
  // Serial.println(isFiring);
}

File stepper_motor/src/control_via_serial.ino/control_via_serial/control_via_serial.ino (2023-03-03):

/*Example sketch to control a stepper motor with A4988 stepper motor driver and Arduino without a library. More info: https://www.makerguides.com */
#include <ArduinoJson.h>
#include <TimerOne.h>


// Define stepper motor connections and steps per revolution:
#define dirPin 2
#define stepPin 3
#define stepsPerRevolution 200


// Define the initial timer interval in microseconds. Start with max value
#define INITIAL_TIMER_INTERVAL 4294967295;

// Define a timer interval variable
unsigned long timerInterval = INITIAL_TIMER_INTERVAL;
 
/*
* Holds the value of the direction of the motor
* false = Anti clockwise
* true = Clockwise
*/
bool isClockwise = false;

/*
 * Alternates the PIN from HIGH to LOW on each half step
*/
bool alternator = false;

 
/*
* Holds the value of the speed of the motor in RPM
*/
byte rpm = 0;


StaticJsonDocument<512> processSerialInput() {
  int size_ = 0;
  String payload;

  if (Serial.available()) {
    payload = Serial.readStringUntil('\n');
  }

  StaticJsonDocument<512> doc;
  DeserializationError error = deserializeJson(doc, payload);

  if (error) {
//    Serial.println(error.c_str());
    return doc; // return an empty JSON document
  }

//  char buffer[100];
//  serializeJsonPretty(doc, buffer);
//  Serial.println("Received Motor config");
//  Serial.println(buffer);

  return doc;
}


// Define a timer interrupt handler function that will be called at the specified interval
void doHalfMotorStep() {
  Serial.print("Updating motor State with timer: ");
  
  Serial.print("Timer interval is: ");
  Serial.println(timerInterval);

  Serial.print("Direction: ");
  Serial.print(isClockwise);
  Serial.print(", RPM: ");
  Serial.print(rpm);
  Serial.print(", alternator: ");
  Serial.println(alternator);
  
  digitalWrite(stepPin, alternator ? LOW : HIGH);
  
}


void setup() {
  // Start serial for communication
  Serial.begin(9600);
  // Declare pins as output:
  pinMode(stepPin, OUTPUT);
  pinMode(dirPin, OUTPUT);
  Serial.println("Send Commands !");

  // Set up the timer interrupt
  Timer1.initialize(timerInterval);  // set the initial timer interval
  Timer1.attachInterrupt(doHalfMotorStep);   // attach the interrupt handler function
}


void loop() {
//  Serial.println("Doing Loop");
  
  StaticJsonDocument<512> motorDetails = processSerialInput();

  if (motorDetails.containsKey("isClockwise")) {
    isClockwise = motorDetails["isClockwise"];
    if (isClockwise) {
      digitalWrite(dirPin, HIGH);
    }
    else {
      digitalWrite(dirPin, LOW);
    }
  }


  if (motorDetails.containsKey("rpm")) {
    
    rpm = motorDetails["rpm"];
    Serial.print("rpm: ");
    Serial.println(rpm);

    float revsPerSecond = rpm / 60.0f;
    Serial.print("revsPerSecond: ");
    Serial.println(revsPerSecond);

    float milliSecondsPerStep = (1/revsPerSecond) * 100000;
    Serial.print("milliSecondsPerStep: ");
    Serial.println(milliSecondsPerStep);
 
    // We divide the interval by 2 so that we can switch the motor from High to low within one step
    timerInterval = milliSecondsPerStep / 2;
    Serial.print("timerInterval: ");
    Serial.println(timerInterval);
    Timer1.setPeriod(timerInterval);
 
  }


//  // Check if the timer has fired
//  if (timerCounter > 0) {
//    // Do something when the timer has fired
//    Serial.println("Timer fired!");
//    digitalWrite(stepPin, HIGH);
//    digitalWrite(stepPin, LOW);
//    // Reset the timer counter
//    timerCounter = 0;
//
//    // Change the timer interval to a new value
////    timerInterval = random(500, 2000);
//    
//  }



 
//  delayMicroseconds(2000);;

//  // Spin the stepper motor 1 revolution slowly:
//  for (int i = 0; i < stepsPerRevolution; i++) {
//    // These four lines result in 1 step:
//    digitalWrite(stepPin, HIGH);
//    delayMicroseconds(2000);
//    digitalWrite(stepPin, LOW);
//    delayMicroseconds(2000);
//  }
//
//  delay(1000);
//
//  // Set the spinning direction counterclockwise:
//  digitalWrite(dirPin, LOW);
//
//  // Spin the stepper motor 1 revolution quickly:
//  for (int i = 0; i < stepsPerRevolution; i++) {
//    // These four lines result in 1 step:
//    digitalWrite(stepPin, HIGH);
//    delayMicroseconds(1000);
//    digitalWrite(stepPin, LOW);
//    delayMicroseconds(1000);
//  }
//
//  delay(1000);
//
//  // Set the spinning direction clockwise:
//  digitalWrite(dirPin, HIGH);
//
//  // Spin the stepper motor 5 revolutions fast:
//  for (int i = 0; i < 5 * stepsPerRevolution; i++) {
//    // These four lines result in 1 step:
//    digitalWrite(stepPin, HIGH);
//    delayMicroseconds(500);
//    digitalWrite(stepPin, LOW);
//    delayMicroseconds(500);
//  }
//
//  delay(1000);
//
//  // Set the spinning direction counterclockwise:
//  digitalWrite(dirPin, LOW);
//
//  //Spin the stepper motor 5 revolutions fast:
//  for (int i = 0; i < 5 * stepsPerRevolution; i++) {
//    // These four lines result in 1 step:
//    digitalWrite(stepPin, HIGH);
//    delayMicroseconds(500);
//    digitalWrite(stepPin, LOW);
//    delayMicroseconds(500);
//  }
//
}

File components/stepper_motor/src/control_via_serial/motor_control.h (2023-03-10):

#include <stdint.h>


#ifndef MOTOR_CONTROL_H
#define MOTOR_CONTROL_H


/**
 * BaseTurretSettings struct represents the base settings for a motor
 *
 * @param isClockwise A boolean indicating the direction of the elevation motor. True means clockwise, False means anti-clockwise.
 * @param speed The speed of the elevation motor.
 * @param isFiring A boolean indicating whether the gun is firing.
 */
struct BaseTurretSettings {
    bool isClockwise;
    int speed;
    bool isFiring;
}; 

/**
 * TurretSettings struct extends the BaseTurretSettings struct to include azimuth.
 *
 * @param isClockwise A boolean indicating the direction of the motor. True means clockwise, False means anti-clockwise.
 * @param speed The speed of the motor.
 * @param isFiring A boolean indicating whether the motor is firing.
 * @param azimuth The azimuth angle for the motor.
 */
struct TurretSettings:BaseTurretSettings {
    int azimuth;
};

/**
 * Decode the azimuth value from the encoded command uint8_t.
 *
 * @param encoded_command The encoded command uint8_t.
 * @returns The decoded azimuth value.
 */
int decodeAzimuth(uint8_t encoded_value) {
    return encoded_value - 90;
}

/**
 * Decode the motor settings from the encoded command uint8_t.
 *
 * @param encoded_command The encoded command uint8_t.
 * @returns The decoded motor settings.
 */
BaseTurretSettings decodeValue(uint8_t encoded_command) {
    BaseTurretSettings settings; 
    settings.isClockwise = bool((encoded_command & 0b10000000) >> 7); // Get the 8th bit for clockwise
    settings.isFiring = bool((encoded_command & 0b01000000) >> 6);  // Check the 7th bit for is_firing
    settings.speed = (encoded_command & 0b00001111); // Mask the lower 4 bits for speed
    return settings;
}


int mapRange(int value, int valRange, int newRange, int minVal, int minNewVal) {

   float scaling_factor = (float)valRange / (float)newRange;

   float original_value = ((float)(value - minVal) * scaling_factor) + minNewVal;
   int val = int(original_value);

   return val;
}


TurretSettings decode(uint8_t *encoded_command) {
    TurretSettings motor_command;
    
    uint8_t encoded_value = encoded_command[0];
    // Serial.print("encoded_value: ");
    // Serial.print(encoded_value, BIN);
    motor_command.isClockwise = bool((encoded_value & 0b10000000) >> 7); // Get the 8th bit for clockwise
    motor_command.isFiring = bool((encoded_value & 0b01000000) >> 6);  // Check the 7th bit for is_firing
    motor_command.speed = (encoded_value & 0b00001111); // Mask the lower 4 bits for speed
    // Serial.print(" - speed decoder: ");
    // Serial.print(motor_command.speed);
  
    
    // Serial.print(" - isFiring  ");
    // Serial.print(motor_command.isFiring);
    
    uint8_t azimuth_uint8_t = encoded_command[1];
    motor_command.azimuth =(encoded_command[1] & 0b11111111) - 90; // Scale the azimuth uint8_t back to 0-180
    // Serial.print(" - azimuth  ");
    // Serial.print(motor_command.azimuth);
    return motor_command;
}

#endif

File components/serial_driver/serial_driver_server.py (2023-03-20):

import logging
from http.server import BaseHTTPRequestHandler
from serial_driver_utils import encode
from serial import Serial
import time
import json

class SerialDriverServer(BaseHTTPRequestHandler):
    
    def __init__(self, *args, **kwargs):
        keys_used = ['serial_inst', 'slowest_speed', 'fasted_speed']
        self.properties = {}
        for key in keys_used:
            if key not in kwargs:
                raise Exception(f"Missing required key: {key}")
            else:
                self.properties[key] = kwargs[key]
                del kwargs[key]
  
        BaseHTTPRequestHandler.__init__(self, *args, **kwargs)

        
    def do_GET(self):
        # Send a response
        self.send_response(200)
        self.end_headers()
        
        # Send the response data
        self.wfile.write(b"""
                            Send a POST request to this endpoint with JSON data with the key 'speed' and a value between speed min 0 and max 10.
                            The json can also have a key of 'isClockwise' with a value of true or false for the direction of the motor.
                            """)
    

    def do_POST(self):
        start_time = time.time()
        # Get the content type and content length of the request
        content_length = int(self.headers.get('content-length', 0))
        # Read the request data
        data = self.rfile.read(content_length)
        
        # Parse the JSON data
        json_data = json.loads(data)
        logging.debug("Got Data: " + json.dumps(json_data))
        
        speed_in = json_data.get('speed', 0)
        
        slowest_speed = self.properties.get('slowest_speed')
        fasted_speed = self.properties.get('fasted_speed')
        serial_inst: Serial = self.properties.get('serial_inst')# type: ignore
        
        if speed_in and (speed_in < slowest_speed or speed_in > self.properties.get('fasted_speed')):
                # Send a response
                self.send_response(400)
                self.end_headers()
                # Send the bad request data
                self.wfile.write(f"""
                Received a speed that was outside the min({slowest_speed}) max({fasted_speed}) bounds: {speed_in}
                """.encode())
                return
            
       
        
        logging.debug("Sending before encoding: " + str([round(json_data.get("azimuth_angle", 0)), json_data.get("is_clockwise", False), round(speed_in), json_data['is_firing']]))
        encoded_message = encode(round(json_data.get("azimuth_angle", 0)), json_data.get("is_clockwise", False), round(speed_in), json_data['is_firing'])
        logging.debug("Encoded Message HEX: " + str(encoded_message) + "  BINARY: " + str(bin(encoded_message[0])) + " " + str(bin(encoded_message[1])))
        try:

            serial_inst.write(encoded_message)
            # # Send a response
            self.send_response(200)
            self.end_headers()
            
        except Exception as e:
            logging.error("An exception was thrown:" + str(e) + " " + str(type(e)))
            if serial_inst: serial_inst.close()
            logging.error("SerialDriverServer stopped and Serial Port closed")
            self.send_response(500)
            self.end_headers()
        finally: 
            # Record the time taken to process the frame
            logging.debug("Frame processed in " + str(time.time() - start_time) + " seconds")


        
        

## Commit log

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2023-03-06 Fix the new encoding/decoding over serial
    [control_via_serial.ino, serial_driver.py]
2023-03-06 Fix up the Aruino commands so the elevation is working correctly
    [control_via_serial.ino, serial_driver.py]
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2023-03-07 Successfully get the zenith servo working correctly
    [control_via_serial.ino, serial_driver.py, servo_motor.ino]
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2023-03-08 Fix fault in clockwise behaviour of stepper motor
    [control_via_serial.ino, serial_driver.py]
2023-03-08 Many small fixes before azimuth realization
    [control_via_serial.ino, serial_driver.py]
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2023-03-10 Fix speed by fixing the division that happens in the ai_controller
    [control_via_serial.ino, serial_driver.py]
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2023-03-13 Extract the correct information from the detection box
    [yolov3.cfg]
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2023-03-16 Add error handler on not decoding JSON
    [az-delivery-stepper-script_example.ino, control_via_serial.ino]
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2023-03-18 adapt run script to pipe output and errors from sub processes
    [serial_driver.py, serial_driver_server.py]
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2026-09-13 chore: modernize dependencies and fix ultralytics 8.3+ imports
    The repo was pinned to May-2023 versions and used the ultralytics
    'yolo.utils' namespace, which was removed in 8.1 — two scripts could
    not even import on any current install.
    - requirements.txt: bump all pins to current stable (ultralytics
    8.3.253, opencv-python 4.14, numpy 2.4.6, onnxruntime 1.30, pytest
    8.4, pylint 3.3); drop the duplicate pylint entry
    - openvino-detection.py / opencv_onnx_python.py: replace the removed
    'ultralytics.yolo.utils' imports with 'ultralytics.utils', and
    yaml_load() with the current YAML.load() helper (80 COCO classes
    verified loading)
    - bin/init.sh: conda env python 3.8 (EOL 2024-10) ->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
2026-09-14 perf(detection): default to yolo11n — faster, more accurate than yolov8n
    Measured on the same image (bus.jpg, 640x480, CPU, 30-frame average):
    - yolo11n: 35.6 ms/frame (28.1 FPS)
    - yolov8n: 37.9 ms/frame (26.4 FPS)
    And on quality, yolo11n finds every object yolov8n finds with HIGHER
    confidence, plus one extra person yolov8n missed at conf 0.4:
    - yolo11n: bus 0.938, persons 0.891/0.879/0.853/0.685
    - yolov8n: bus 0.871, persons 0.869/0.853/0.819
    Published COCO benchmarks agree: yolo11n 39.5 mAP vs yolov8n 37.3, with
    19% fewer params (2.6M vs 3.2M) — and the CPU-inference gap widens on
    the Pi-class ARM hardware this turret targets.
    export_model.py default swapped too; ONNX/OpenVINO expor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
2026-09-14 feat(aim): PID controllers for azimuth/elevation with live web tuning UI
    Replaces the hand-tuned proportional heuristics with proper PID control:
    - pid_controller.py: PID with derivative-on-measurement (no setpoint
    kick), clamped integral for anti-windup, output limits. 7 headless tests.
    - tuning_ui.py: dependency-free web UI (stdlib http.server) with live
    sliders for all six gains; changes apply to the control loop on the
    next frame, and /state streams errors/outputs for observability.
    - ai_controller.py: two PIDs (azimuth angle step, elevation speed) driven
    by the same pixel errors the legacy path used; PIDs reset on lost
    target and on connection loss. --no-pid falls back to the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
2026-09-22 fix: py3.14 argparse help crash and camera failure handling
2026-09-22 feat(ui): single-page turret dashboard with live video, runtime modes and live tuning
    - MJPEG stream of the annotated camera feed served by camera_vision
    (stream_server.py), embedded in the tuning UI alongside telemetry
    and controls; --view web|window|none makes the feeds mutually
    exclusive with web as the default
    - Runtime-switchable modes: target type (person/face), tracked face
    IDs (datalist fed by data/targets, lazy-loaded and re-scannable),
    and orchestrator-style presets
    - Live inference/image tuning proxied to camera_vision: imgsz,
    downscale, detect cadence, confidence, loop delay, detector toggles
    - Aim calibration: X/Y target offsets applied to PID errors and the
    on-tar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
2026-09-23 feat(search): autonomous back-and-forth sweep with tunable speed and end easing
    Replaces the legacy constant-rate --search flip with a phase-based
    sinusoidal sweep: zero velocity at each end for natural ease-in/out,
    search_ease shapes the profile (0 = linear with instant reversal,
    1 = sinusoidal, higher = longer dwell at the ends). Sweep speed,
    cycle period, and enable toggle are live-tunable from the web UI and
    yield immediately to normal aiming when a target appears.
2026-09-25 feat: segmentation aiming, manual control, robust command link and UI overhaul
    camera_vision:
    - YOLO segmentation mode (default) aiming at the largest mask blob's
    centroid, with live contour overlay and a distinct diamond marker on
    the aim target only; biggest-body ordering; runtime model swap
    - newline-delimited frames, serialized/cached target-photo encoding
    (concurrent dlib encodes corrupted the native heap), graceful target
    loading, catch-all loop guard and frame-clamped face crops
    - /settings and /targets APIs on the MJPEG stream server
    ai_controller:
    - manual mode (UI sliders, joystick polling, arrow-key hooks) with
    delta-based azimuth; search sweep uses a sinusoidal velocit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
    [serial_driver.py, serial_driver_utils.py]
2026-09-25 chore(cad): collect gun/turret CAD sources into cad/
    Moves all CAD part files for the gun and turret out of
    mechanical_component into a dedicated cad/ directory:
    - Fusion/SolidWorks assemblies and bases (Nerf_gun, cannon/base, base v1-v9)
    - arduino-uno-case printed parts (STL/SLDPRT/STEP)
    - SG90 servo model step
    [Cannon Base.f3d, Nerf_gun.f3d, Tower Pro SG90 Servo v7.step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]
2026-09-25 chore(cad): group CAD files into per-part subdirectories
    cad/gun (Nerf gun model), cad/base (cannon and base revisions),
    cad/arduino-uno-case and cad/servo-sg90 now also hold their
    reference images so each part keeps its files together.
    [Cannon Base.f3d, Nerf_gun.f3d, base v1.f3d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]
2026-09-25 feat(cad): parametric NEMA 17 (17HS4023) stepper motor holder
    OpenSCAD face plate with the standard 31 mm bolt pattern, a drop-in
    cradle for the motor body with a wire exit, and slotted side flanges.
    All dimensions are parameters at the top of the file; exports to STL
    for printing (render verified as a single watertight volume).
    [stepper_holder.scad]
2026-09-25 feat(cad): put stepper holder clamps on the front face
    Mounting tabs now sit on the front face as clamp tabs protruding
    forward (+Z) with through-holes for bolting to a front panel.
    Side tabs remain available via flange_orientation = "sides".
    [stepper_holder.scad]
2026-09-25 feat(cad): stepper holder as a front plate with corner screws and motor cutout
    Replaces the tabbed bracket with a front mounting plate: four corner
    M3 screws, the NEMA 17 bolt pattern and boss/shaft cutout, plus an
    optional body cradle behind the plate (toggle with include_cradle).
    [stepper_holder.scad]
2026-09-25 fix(cad): stepper holder cradle depth matches measured 32 mm motor body
    [stepper_holder.scad]
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2026-09-25 chore(cad): trim stepper holder plate to 60 mm square with 4 mm corner hole inset
    [stepper_holder.scad]
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2026-09-25 chore(cad): position stepper wire slot 2-8 mm from the back, 8 mm wide
    [stepper_holder.scad]
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2026-09-25 feat(cad): octagonal motor cavity matching the stepper's tapered corners
    The NEMA 17 body has chamfered corners (8 sides, ~6 mm corner flats),
    so the cradle cavity is now an octagon across the 42.3 mm flats with
    45 degree corner cuts instead of a square. STL re-exported.
    [stepper_holder.scad, stepper_holder.stl]
2026-09-25 feat(cad): chamfer the cradle's outer vertical corners to match the motor
    The cradle outer shell now uses the same octagonal profile as the
    cavity, so the holder keeps a uniform wall and the vertical edges are
    chamfered instead of sharp. STL re-exported.
    [stepper_holder.scad, stepper_holder.stl]
2026-09-25 feat(cad): chamfer base plate corners and pull mount holes inward
    Base plate now uses the same octagonal corner profile as the cradle,
    and the corner mount holes are inset 8 mm instead of 4 mm so there is
    more material around them. STL re-exported.
    [stepper_holder.scad, stepper_holder.stl]
2026-09-25 fix(cad): move stepper wire exit to the opposite side
    [stepper_holder.scad, stepper_holder.stl]
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2026-09-25 chore(cad): move base plate mount holes 1 mm closer to the edges
    [stepper_holder.scad, stepper_holder.stl]
2026-09-25 chore(cad): move base plate mount holes another 1 mm toward the edges
    [stepper_holder.scad, stepper_holder.stl]
2026-09-25 feat(ui): mode-aware sections, server-side render and no-cache headers
    Collapses every panel by default, hides auto-only sections (PIDs,
    target mode, calibration, search, inference) in manual mode and the
    manual panel in auto mode, renders mode and PID values server-side so
    the first paint is correct, adds no-store headers, and fixes the page
    JS (duplicate declaration and use-before-init) that stopped telemetry
    from loading.
2026-09-25 chore(cad): move stepper wire exit toward the plate end of the cradle
    [stepper_holder.scad, stepper_holder.stl]
2026-09-25 feat(cad): expose wire cutout as parameters and space it 4 mm further from the plate
    Adds [Wire cutout] parameters (distance from plate, width, height and
    which wall) and moves the slot to 10 mm from the plate end.
    [stepper_holder.scad, stepper_holder.stl]
2026-09-25 feat(cad): explicit motor clearance parameter and 42 mm motor face
    The cavity is now motor_face + motor_clearance (0.6 mm total, 0.3 mm
    per side) so the fit can be tuned; motor face set to the measured 42 mm.
    [stepper_holder.scad, stepper_holder.stl]
2026-09-25 feat(cad): split holder into inner plate and outer cradle pieces
    Adds a part selector (both/plate/cradle). The inner end plate carries
    the motor cutout and corner screws; the outer cradle wraps the motor
    body. Both STLs are exported separately; 'both' lays them side by side.
    [stepper_cradle.stl, stepper_holder.scad, stepper_plate.stl]
2026-09-25 feat(cad): two end plates - inner motor plate and outer far-end plate
    Inner plate is bore-sized and bolts to the motor face (fully inside
    the cradle); outer plate caps the far end on the outside and carries
    the four corner panel screws. Cradle unchanged; part selector now
    renders all/inner/outer/cradle, and each piece is exported as its own
    STL.
    [stepper_cradle.stl, stepper_holder.scad, stepper_holder.stl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]
2026-09-25 fix(cad): align the three pieces on the Z axis in the combined layout
    [stepper_holder.scad, stepper_holder.stl]
2026-09-25 feat(cad): open the outer plate's middle so the motor shape passes through
    [stepper_holder.scad, stepper_holder.stl, stepper_outer_plate.stl]
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2026-09-25 fix(cad): assembled layout attaches both plates to the cradle's ends
    [stepper_holder.scad, stepper_holder.stl]
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2026-09-25 chore(cad): enlarge screw holes to 3.8 mm for print clearance
    [stepper_cradle.stl, stepper_holder.scad, stepper_holder.stl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]
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2026-09-26 feat(cad): round the gun cradle's inside and outside corners
    Vertical corners now use offset rounded rectangles: 4 mm inside the
    cavity, 6 mm on the outside of the tray.
    [gun_cradle.scad, gun_cradle.stl]
2026-09-26 chore(cad): remove the gun cradle base so it is open at both ends
    [gun_cradle.scad, gun_cradle.stl]
2026-09-26 feat(cad): open one short side of the gun cradle completely
    [gun_cradle.scad, gun_cradle.stl]
2026-09-26 fix(cad): open a short (±Y) side of the gun cradle, not a long side
    [gun_cradle.scad, gun_cradle.stl]
2026-09-26 fix(cad): square off the gun cradle wall ends at the open side
    [gun_cradle.scad, gun_cradle.stl]
2026-09-26 fix(cad): square the inner cavity corners at the gun cradle's open end
    [gun_cradle.scad, gun_cradle.stl]
2026-09-26 feat(cad): add a mounting tab at the bottom of each side of the gun cradle
    [gun_cradle.scad, gun_cradle.stl]
2026-09-26 feat(cad): make the cradle mount bores 10 mm for the mounting pipe
    [gun_cradle.scad, gun_cradle.stl]
2026-09-26 feat(cad): replace cradle tabs with 16 mm pipe sockets bored 10 mm
    Each side now has a socket tube at the bottom that a 10 mm pipe
    slides into, instead of a flat tab with a hole.
    [gun_cradle.scad, gun_cradle.stl]
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2026-09-26 fix(cad): define socket height as a fraction so the sockets render centred
    [gun_cradle.scad, gun_cradle.stl]
2026-09-26 feat(cad): place cradle pipe sockets 100 mm along Y from the closed end
    [gun_cradle.scad, gun_cradle.stl]
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2026-09-26 feat(cad): split-clamp pipe sockets instead of grub screws
    Each socket now has a lengthwise slit between two ears, an M3 bolt
    hole through the ears and a trapped hex-nut pocket, so tightening the
    bolt clamps the socket onto the metal pipe (no threads in plastic).
    STL re-exported.
    [gun_cradle.scad, gun_cradle.stl]
2026-09-26 feat(cad): capsule opening in the gun cradle's closed short wall
    35 x 10 mm stadium slot, centred across the width, starting 13 mm up
    from the bottom edge.
    [gun_cradle.scad, gun_cradle.stl]
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2026-09-26 feat(cad): plain gun cradle variant without clamp tightening holes
    Same cradle geometry in its own file (gun_cradle_plain.scad) but with
    plain slip-fit pipe sockets instead of the split clamp.
    [gun_cradle_plain.scad, gun_cradle_plain.stl]
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2026-09-26 fix(cad): plain cradle is a clean 70x60x15 tray (sockets and capsule removed)
    [gun_cradle_plain.scad, gun_cradle_plain.stl]
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2026-09-26 fix(cad): 40 variant cavity is 40 (short) x 60 (long) x 15 mm inner
    [gun_cradle.3mf, gun_cradle_plain_40.scad, gun_cradle_plain_40.stl]
2026-09-26 chore(cad): swap the 40/60 axes on the small plain cradle
    [gun_cradle_plain_40.scad, gun_cradle_plain_40.stl]
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2026-09-26 fix(cad): place the cradle M3 holes through the X-axis end walls
    [gun_cradle_plain_40.scad, gun_cradle_plain_40.stl]
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2026-09-26 chore(cad): change the cradle end-wall holes to M2 clearance (2.4 mm)
    [gun_cradle_plain.scad, gun_cradle_plain.stl, gun_cradle_plain_40.scad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]
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2026-09-26 fix(cad): overlap the clamp ears into the socket tube so they fuse
    [gun_cradle.scad, gun_cradle.stl]
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
